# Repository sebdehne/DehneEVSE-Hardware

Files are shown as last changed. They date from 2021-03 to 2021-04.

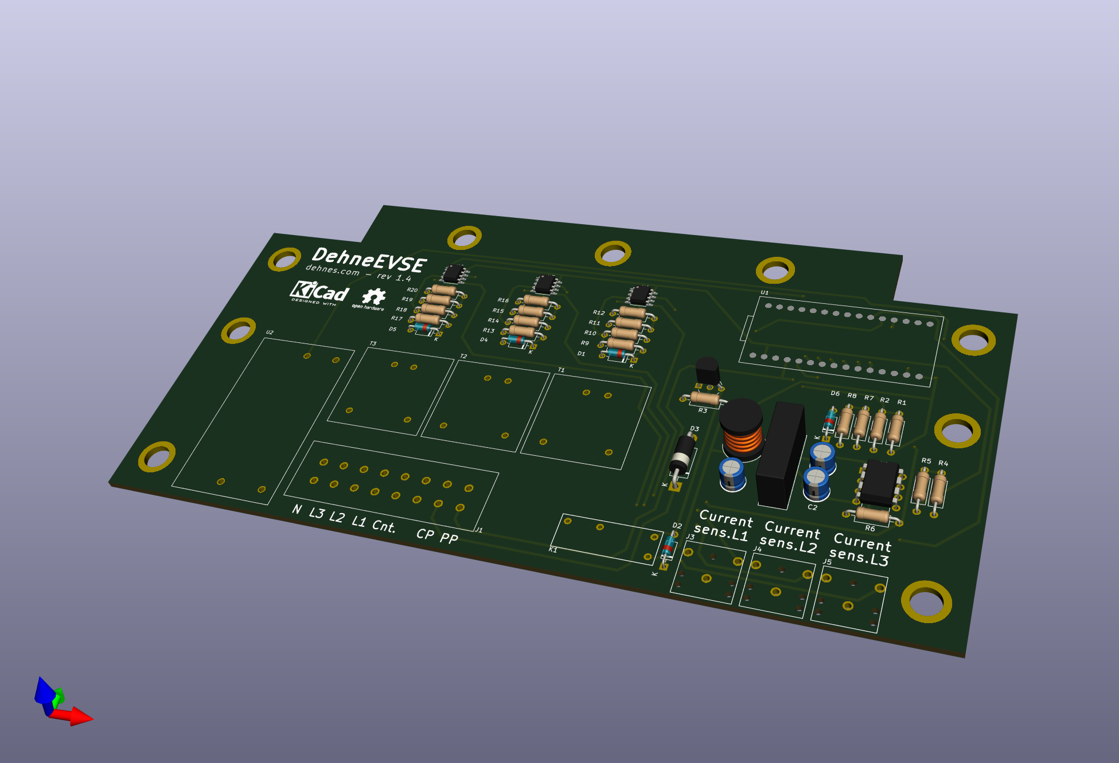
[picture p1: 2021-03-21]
Media/PCB-3d-view.png

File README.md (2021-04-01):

# DehneEVSE Open source EV Charging Station - Hardware

KiCad design files of a controller board for Type-2 charging (IEC 61851) of EVs.

See [Schematic](Media/schematic.pdf) and [3d-view](Media/PCB-3d-view.png).

See [DehneEVSE EV Charging Station](https://dehnes.com/electronics/2021/03/31/dehneevse_charging_station.html) for more 
information on the entire setup.

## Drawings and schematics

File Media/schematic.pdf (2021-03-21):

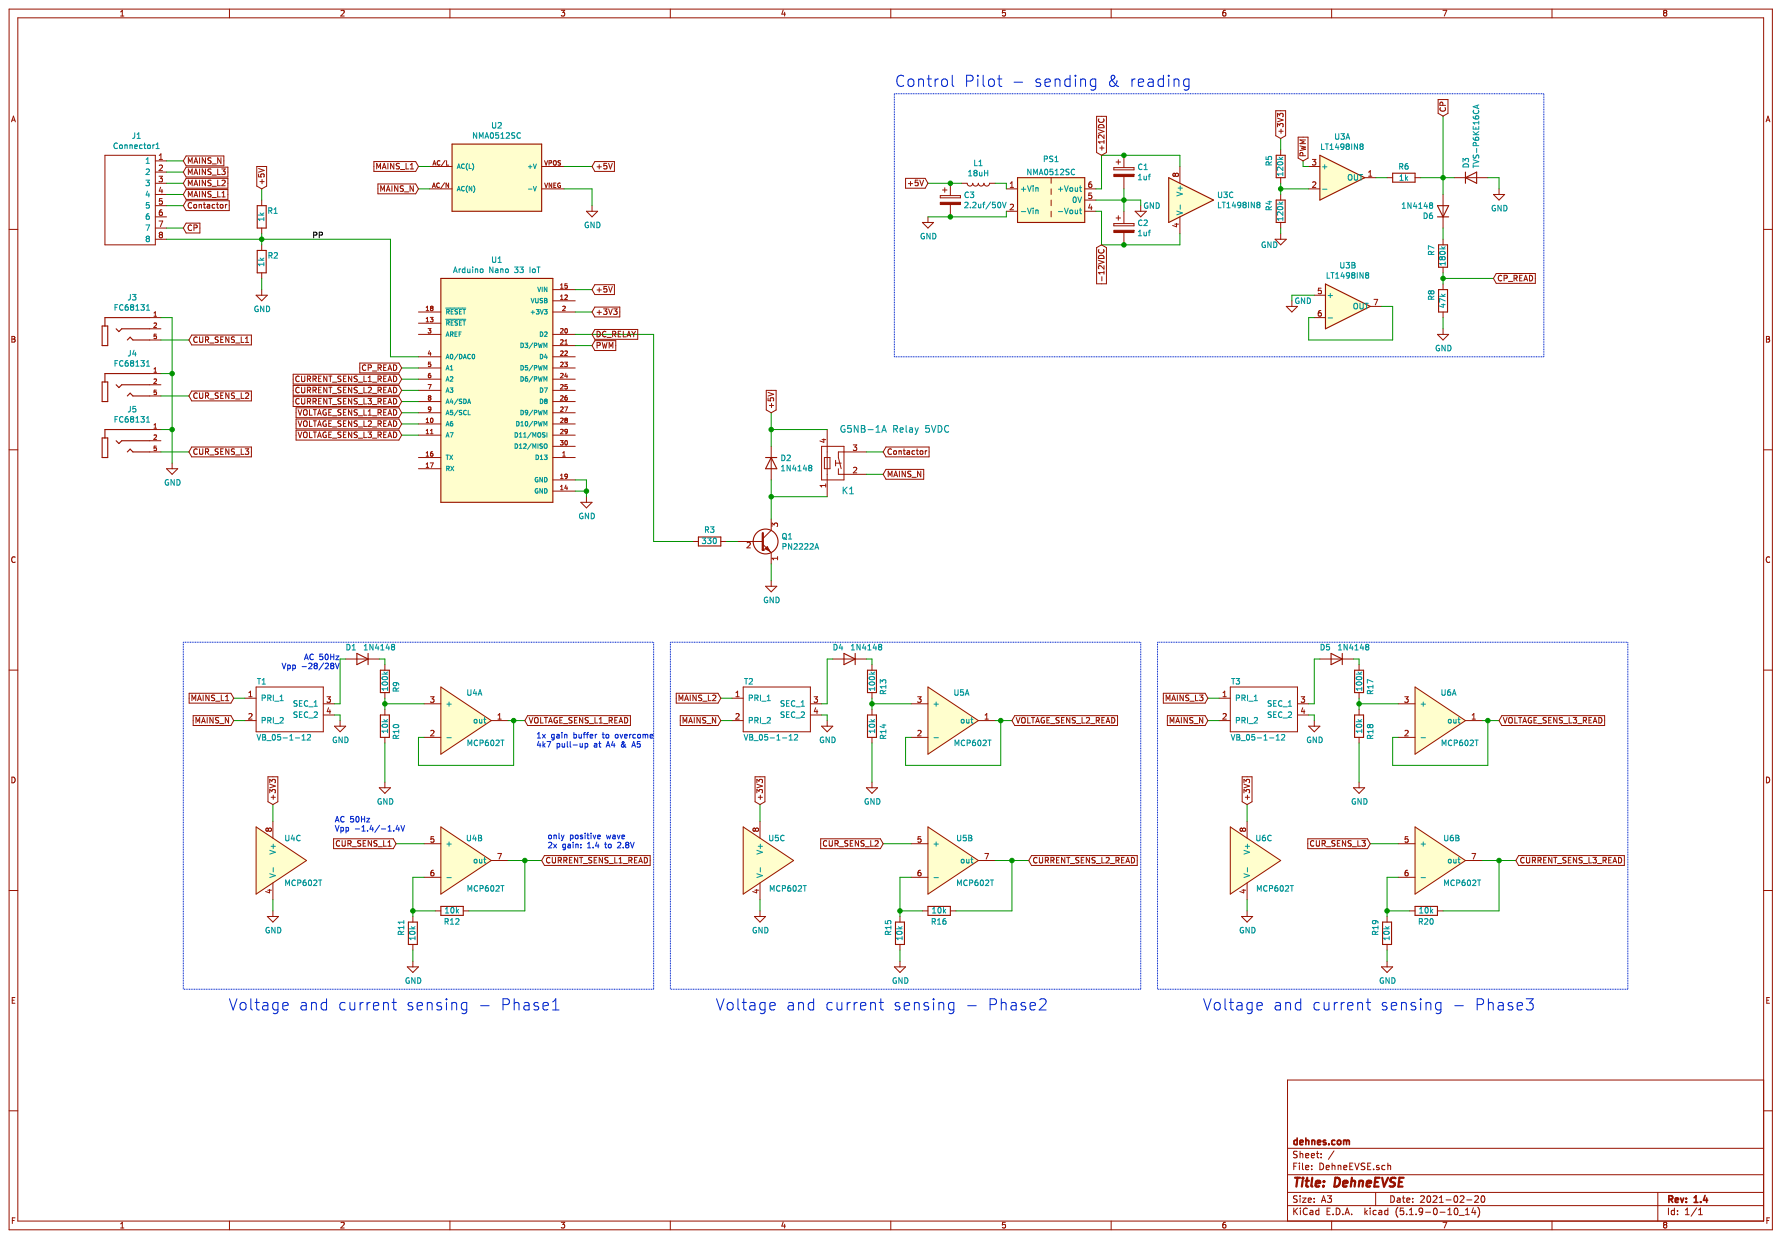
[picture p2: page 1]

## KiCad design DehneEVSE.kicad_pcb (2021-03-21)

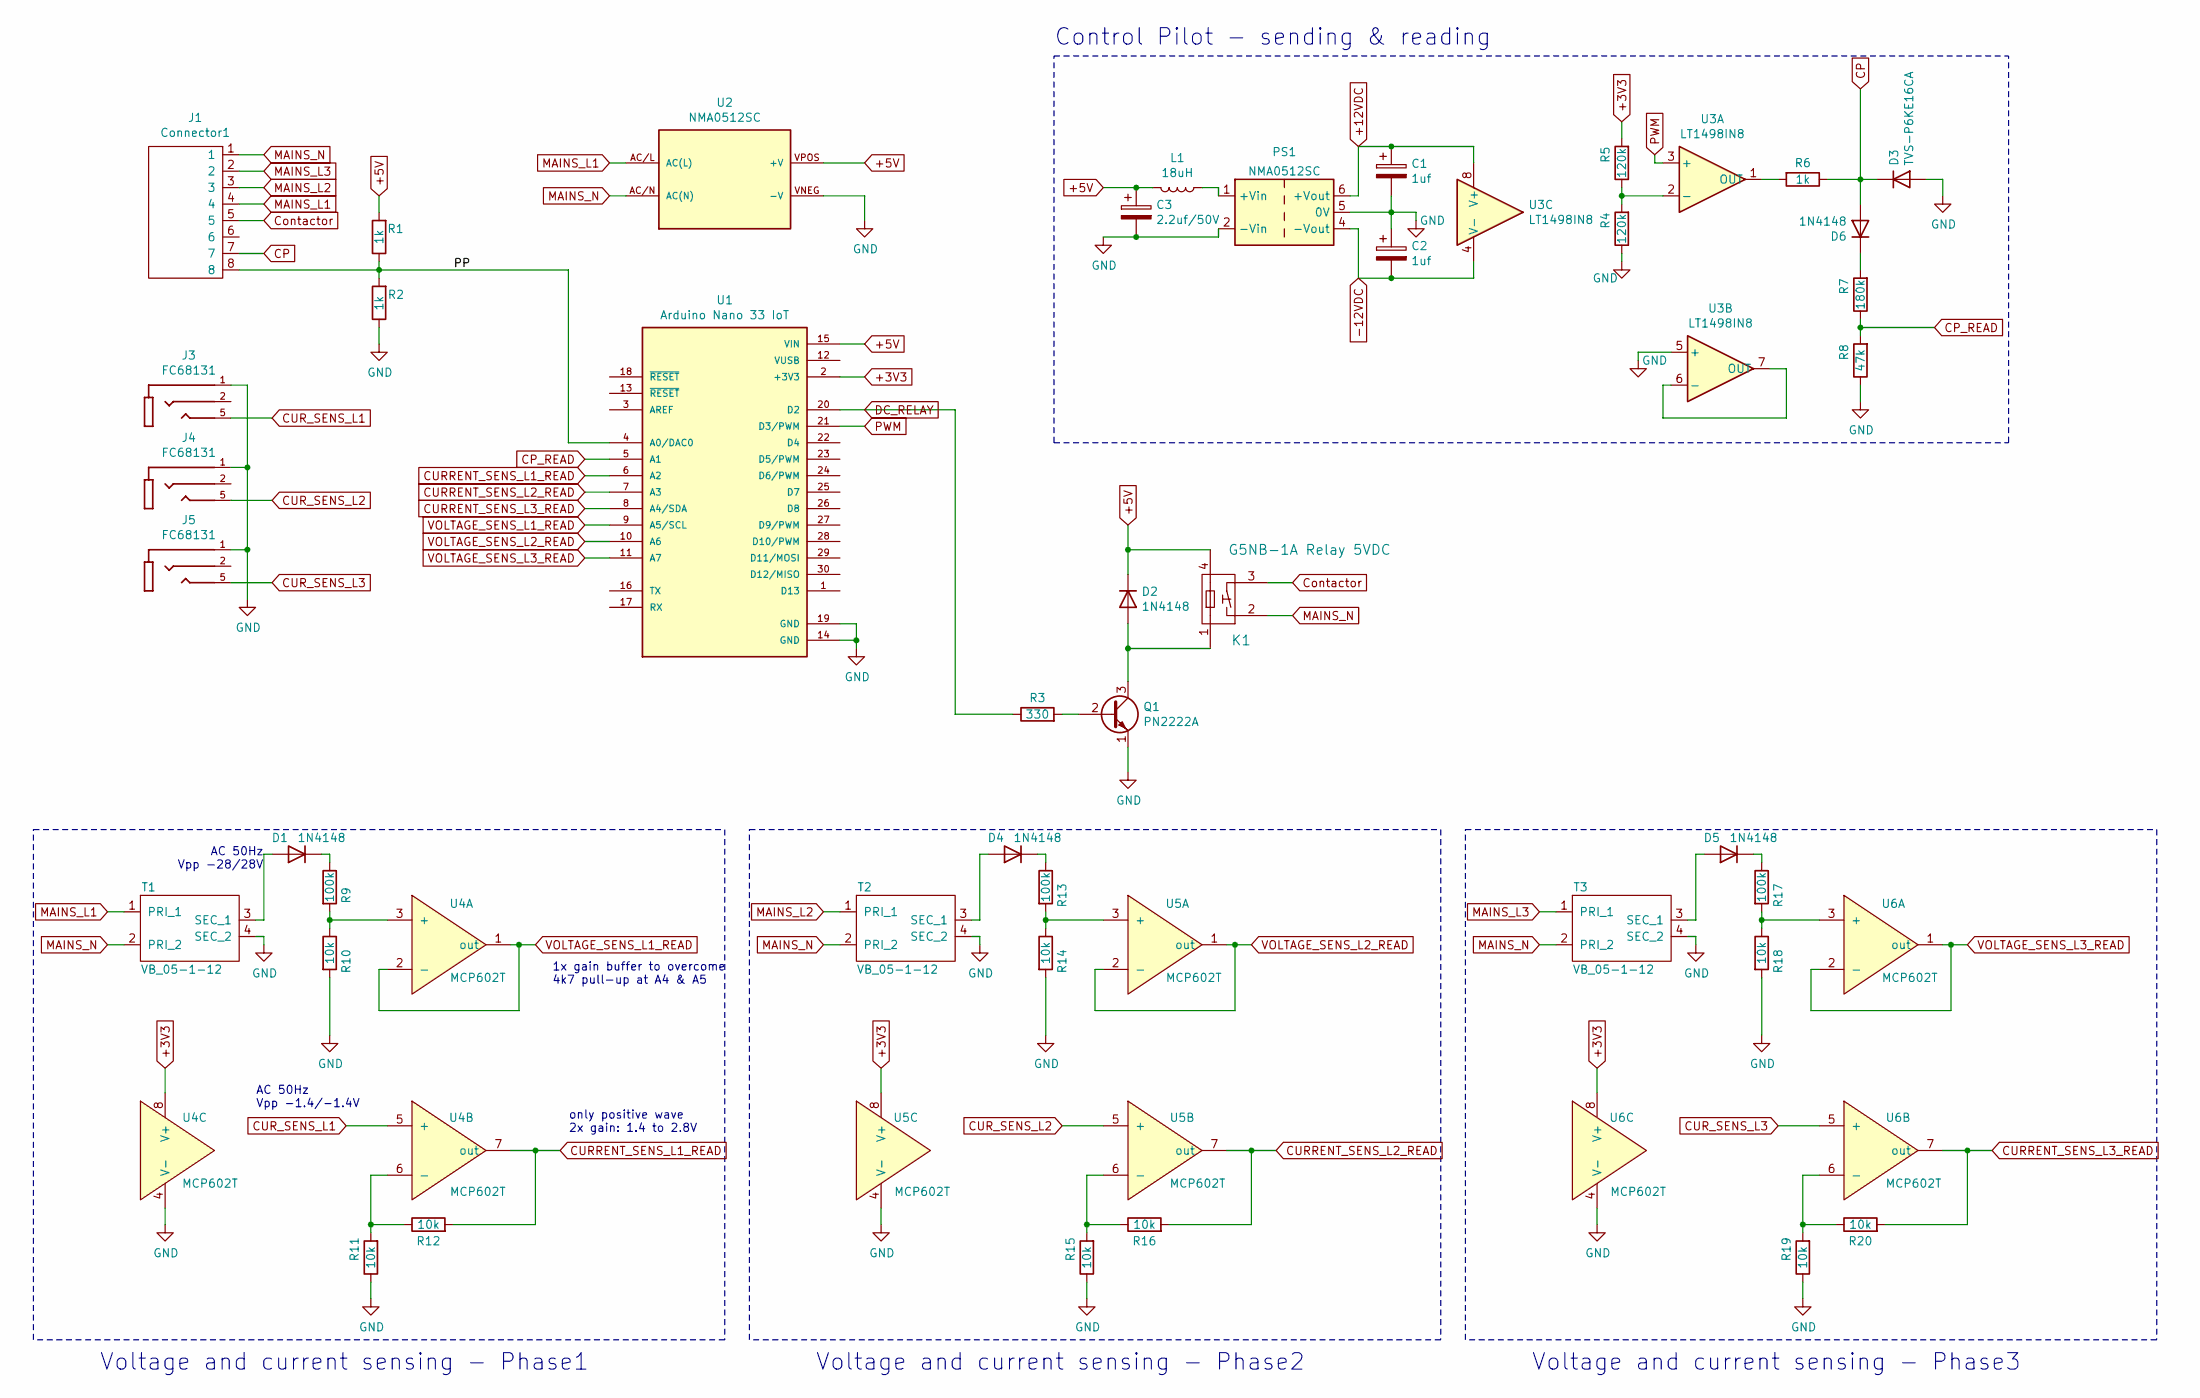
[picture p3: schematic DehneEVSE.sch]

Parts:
C1, C2: 1uf; CP_Radial_D5.0mm_P2.50mm
C3: 2.2uf/50V; CP_Radial_D5.0mm_P2.50mm
D1, D2, D4, D5, D6: 1N4148; D_DO-35_SOD27_P7.62mm_Horizontal
D3: TVS-P6KE16CA; D_DO-15_P12.70mm_Horizontal
J1: Connector1; conn_08x02_wago
J3, J4, J5: FC68131; CLIFF_FC68131; PARTREV 5
K1: G5NB-1A Relay 5VDC; Omron-GSNB-1A
L1: 18uH; L_Radial_D8.7mm_P5.00mm_Fastron_07HCP
PS1: NMA0512SC; Converter_DCDC_XP_POWER-IAxxxxS_THT
Q1: PN2222A; TO-92_Inline_Wide
R1, R2, R6: 1k; R_Axial_DIN0207_L6.3mm_D2.5mm_P10.16mm_Horizontal
R3: 330; R_Axial_DIN0207_L6.3mm_D2.5mm_P10.16mm_Horizontal
R4, R5: 120k; R_Axial_DIN0207_L6.3mm_D2.5mm_P10.16mm_Horizontal
R7: 180k; R_Axial_DIN0207_L6.3mm_D2.5mm_P10.16mm_Horizontal
R8: 47k; R_Axial_DIN0207_L6.3mm_D2.5mm_P10.16mm_Horizontal
R9, R13, R17: 100k; R_Axial_DIN0207_L6.3mm_D2.5mm_P10.16mm_Horizontal
R10, R11, R12, R14, R15, R16, R18, R19, R20: 10k; R_Axial_DIN0207_L6.3mm_D2.5mm_P10.16mm_Horizontal
T1, T2, T3: VB_05-1-12
U1: Arduino Nano 33 IoT; Arduino_Nano_33_iot__SMT
U2: NMA0512SC; CONV_IRM-05-5
U3: LT1498IN8; DIP-8_W7.62mm
U4, U5, U6: MCP602T; SOIC-8_3.9x4.9mm_P1.27mm

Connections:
+3V3: R5.2, U1.2 (+3V3), U4.8 (V+), U5.8 (V+), U6.8 (V+)
+5V: C3.1, D2.1 (K), K1.4, L1.2, R1.2, U1.15 (VIN), U2.VPOS (+V)
+12VDC: C1.1, PS1.6 (+Vout), U3.8 (V+)
-12VDC: C2.2, PS1.4 (-Vout), U3.4 (V-)
/PP: J1.8, R1.1, R2.2, U1.4 (A0/DAC0)
CP: D3.1 (K), D6.2 (A), J1.7, R6.1
CP_READ: R7.1, R8.2, U1.5 (A1)
CURRENT_SENS_L1_READ: R12.2, U1.6 (A2), U4.7 (out)
CURRENT_SENS_L2_READ: R16.2, U1.7 (A3), U5.7 (out)
CURRENT_SENS_L3_READ: R20.2, U1.8 (A4/SDA), U6.7 (out)
CUR_SENS_L1: J3.5, U4.5 (+)
CUR_SENS_L2: J4.5, U5.5 (+)
CUR_SENS_L3: J5.5, U6.5 (+)
Contactor: J1.5, K1.3
DC_RELAY: R3.1, U1.20 (D2)
GND: C1.2, C2.1, C3.2, D3.2 (A), J3.1, J4.1, J5.1, PS1.2 (-Vin), PS1.5 (0V), Q1.1 (E), R2.1, R4.1, R8.1, R10.2, R11.1, R14.2, R15.1, R18.2, R19.1, T1.4 (SEC_2), T2.4 (SEC_2), T3.4 (SEC_2), U1.14 (GND), U1.19 (GND), U2.VNEG (-V), U3.5 (+), U4.4 (V-), U5.4 (V-), U6.4 (V-)
MAINS_L1: J1.4, T1.1 (PRI_1), U2.AC/L (AC(L))
MAINS_L2: J1.3, T2.1 (PRI_1)
MAINS_L3: J1.2, T3.1 (PRI_1)
MAINS_N: J1.1, K1.2, T1.2 (PRI_2), T2.2 (PRI_2), T3.2 (PRI_2), U2.AC/N (AC(N))
unnamed: D1.1 (K), R9.1
unnamed: D1.2 (A), T1.3 (SEC_1)
unnamed: D2.2 (A), K1.1, Q1.3 (C)
unnamed: D4.1 (K), R13.1
unnamed: D4.2 (A), T2.3 (SEC_1)
unnamed: D5.1 (K), R17.1
unnamed: D5.2 (A), T3.3 (SEC_1)
unnamed: D6.1 (K), R7.2
unnamed: L1.1, PS1.1 (+Vin)
unnamed: Q1.2 (B), R3.2
unnamed: R4.2, R5.1, U3.2 (-)
unnamed: R6.2, U3.1 (OUT)
unnamed: R9.2, R10.1, U4.3 (+)
unnamed: R11.2, R12.1, U4.6 (-)
unnamed: R13.2, R14.1, U5.3 (+)
unnamed: R15.2, R16.1, U5.6 (-)
unnamed: R17.2, R18.1, U6.3 (+)
unnamed: R19.2, R20.1, U6.6 (-)
unnamed: U3.6 (-), U3.7 (OUT)
PWM: U1.21 (D3/PWM), U3.3 (+)
VOLTAGE_SENS_L1_READ: U1.9 (A5/SCL), U4.1 (out), U4.2 (-)
VOLTAGE_SENS_L2_READ: U1.10 (A6), U5.1 (out), U5.2 (-)
VOLTAGE_SENS_L3_READ: U1.11 (A7), U6.1 (out), U6.2 (-)

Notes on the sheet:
Control Pilot - sending & reading
Voltage and current sensing - Phase1
Voltage and current sensing - Phase2
Voltage and current sensing - Phase3
AC 50Hz Vpp -1.4/-1.4V
only positive wave 2x gain: 1.4 to 2.8V
1x gain buffer to overcome 4k7 pull-up at A4 & A5
AC 50Hz Vpp -28/28V

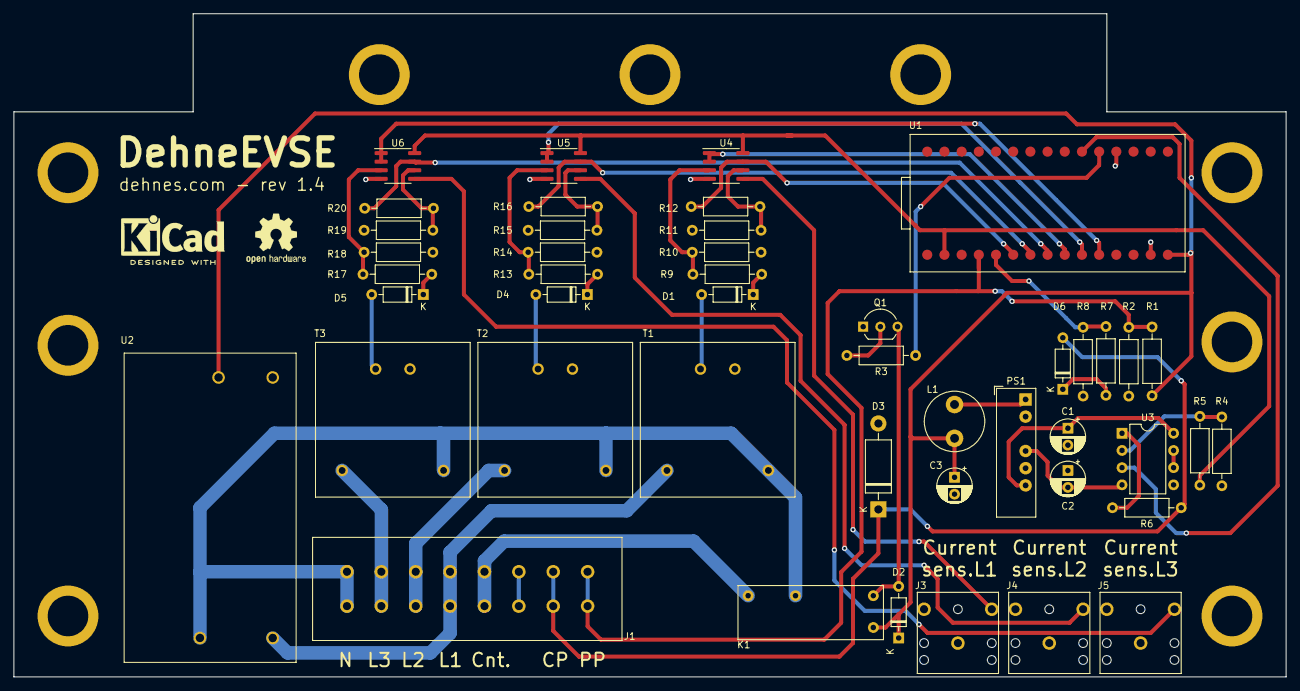
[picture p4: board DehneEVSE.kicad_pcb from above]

Board: 2 copper layers, 188.0 x 98.0 mm, 46 parts (0 on the bottom side), 43 nets.

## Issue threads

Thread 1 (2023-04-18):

Q1 on PCB

Ralle001, 2023-04-18:
The Q1 component is not listed in the BOM list. Can you tell me what is the component?

sebdehne, 2023-04-18:
It is listed in the schematic [Schematic](https://github.com/sebdehne/DehneEVSE-Hardware/blob/master/Media/schematic.pdf)

Closed 2023-04-18.

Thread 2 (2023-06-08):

Wiring

Ralle001, 2023-06-08:
Can you tell me which wire goes where?
Because it is really confusing from the type to till the pcb

sebdehne, 2023-06-08:
Incoming power (1, 2 or 3 phase) -> Type-B GFCI -> Contactor -> Type2 socket

But hey, if you do not know how to connect those wires, I think it is safest if you ask an electrician to connect those wires for you.

Closed 2023-06-08.

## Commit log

2021-02-21 revision 1
    [EVChargingStation.kicad_pcb, EVChargingStation.sch]
2021-02-21 schematic pdf
2021-02-22 changed drill holes for 3.5mm minijack connector
    [EVChargingStation.kicad_pcb]
2021-02-22 revision 1.2 - added connection to PE
    [EVChargingStation.kicad_pcb, EVChargingStation.sch]
2021-02-28 Updated some resistor values & Readme
    [EVChargingStation.sch]
2021-03-03 Working on revision 1.3
    [EVChargingStation.sch]
2021-03-08 PCB layout for rev 1.3
    [EVChargingStation.kicad_pcb, EVChargingStation.sch]
2021-03-10 revision 1.3 done
    [EVChargingStation.kicad_pcb, EVChargingStation.sch]
2021-03-11 renamed to DehneEVSE
    [DehneEVSE.kicad_pcb, DehneEVSE.sch]
2021-03-11 minor updates
    [DehneEVSE.sch]
2021-03-13 updated footprint arduino
    [DehneEVSE.kicad_pcb]
2021-03-20 rev 1.4
    [DehneEVSE.kicad_pcb, DehneEVSE.sch]
2021-03-21 rev 1.4 - printout
    [DehneEVSE.sch]
